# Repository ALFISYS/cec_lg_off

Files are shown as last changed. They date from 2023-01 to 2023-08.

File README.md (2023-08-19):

# cec\_lg\_off

**cec\_lg\_off** is a hardware addon to make old LG smart TVs with WebOS be able to be turned off with command over HDMI device connected to it. 

It is a tiny device that you connect to your TV's interfaces. 

**cec\_lg\_off** monitors commands that other devices connected to your TV over HDMI, and when it detects someone sent CEC `STANDBY` command to TV, it turns off TV

### Device photos

#### Working prototype.

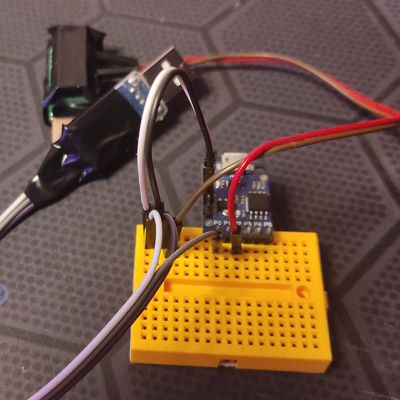
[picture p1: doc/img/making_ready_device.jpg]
Prototype


*brown wire connected wrong hole on this photo. Is should be connected to 2nd column (black wires)*

### Making of device

All process of building this device from AliExpress modules is described in ["making  from modules" document](doc/MAKING_MODULES.md).

### Questions

#### *Do I need to connect the device to the HDMI cable break?*

No. You need to connect it to any free HDMI port on your TV. Control commands are sent over HDMI CEC line (Pin13 on HDMI cable). This line is electrically connected together through all HDMI devices that connected together. This means when some device talks using CEC to other device, everyone hear them.

#### *Can I connect USB cable to power adapter or power bank?*

No. You need to connect it to any free USB port on your TV. When device detects STANDBY command sent to TV on CEC line, it sends equal command (power off) through USB-SERIAL adapter. Also device powers from it. 

### Bill of materials (BOM) / List of materials (LOM)

Materials for building device from modules are listed in separate [List of materials (LOM) document](doc/LOM_MODULES.md).

### Building firmware

It's recommended to configure MCU to run at 16 MHz (`F_CPU = 16000000`).
If you're using **DigiSpark USB**, configuration supports 16.5 MHz CPU.
For other `F_CPU` values, please add your F_CPU to PowerShell script [helper_constants.ps1](firmware/attiny25/helper_constants.ps1) and run it to get contents for [constants.h](firmware/attiny25/src/cec_mon_constants.h).

### Other documents

Documents used while developing this device, such as MCU datasheet, HDMI specification, etc. are located under [`doc`](doc) folder. 

### CEC emulator

A tiny emulator that sends STANDBY command periodically is located as Arduino project under [`cec_emulator_firmware`](cec_emulator_firmware) folder

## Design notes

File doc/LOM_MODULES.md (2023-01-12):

# cec\_lg\_off LOM for DIY device from modules.

### List of materials (LOM) for device

Same as BOM, but with instructions and no prices.

* **PL2303** USB-TTL (USB-SERIAL) adapter.
	* ⚠️ **WARNING**: PL2303HX, PL2303TA are recommended. Non-PL* alternatives are not allowed.
	* Before buying next, ensure your adapter has VID 067B and PID 2303
	* Before buying next, ensure your TV recognizes PL2303 adapter
		* Turn TV on
		* Plug PL2303 adapter into TV USB port
		* Ensure message apperared without words like "unknown" or "unrecognized"
	* Links: [🔗 AliExpress](https://aliexpress.com/item/32531899568.html)
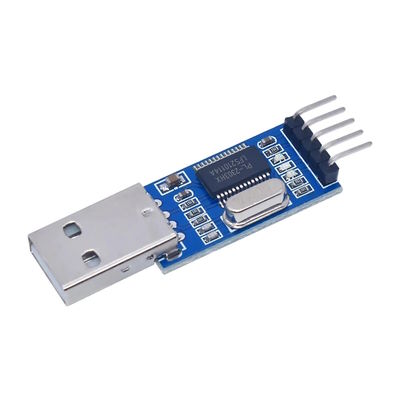
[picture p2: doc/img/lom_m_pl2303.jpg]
PL2303 USB-TTL Board
	* Image: 
* **DigiSpark USB** developement board
	* Prefer board with female USB connector.
	* Links: [🔗 AliExpress](https://aliexpress.com/item/32584084654.html), [🔗 AliExpress](https://aliexpress.com/item/32807895683.html)
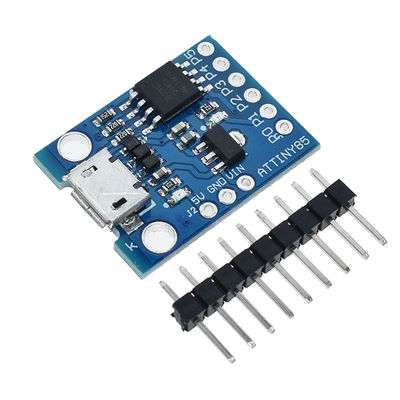
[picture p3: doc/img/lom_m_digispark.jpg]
Digispark Attiny85 dev board
	* Image: 
* **HDMI A male connector with screw terminals**
	* Links: [🔗 AliExpress](https://aliexpress.com/item/1005001515985184.html)
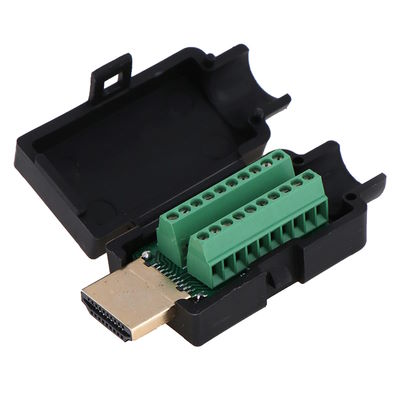
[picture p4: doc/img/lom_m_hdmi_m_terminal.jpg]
HDMI male connector withj screw terminals
	* Image: 
* **Solderless mini breadboard**
	* Links: [🔗 AliExpress](https://aliexpress.com/item/32649320530.html)
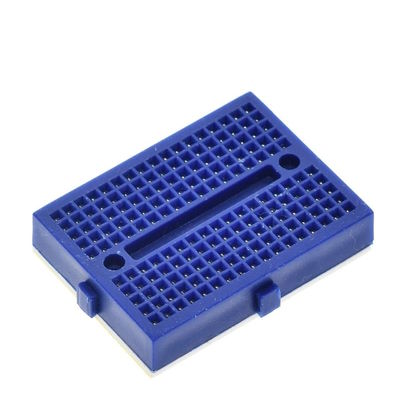
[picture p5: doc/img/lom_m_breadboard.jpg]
Solderless mini breadboard
	* Image: 
* **DuPont cables**
	* You'll need 2 long cables `male-male` and 5 `male-female`
	* Links: [🔗 AliExpress](https://aliexpress.com/item/32825558073.html)
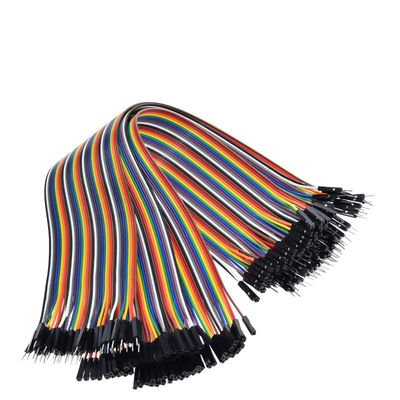
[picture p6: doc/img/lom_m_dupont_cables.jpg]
	* Image: 
* Some good insulating tape
* Soldering iron

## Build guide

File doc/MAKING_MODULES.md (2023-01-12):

### Bill of materials (BOM) / List of materials (LOM)

Materials for building device from modules are listed in separate [List of materials (LOM) document](LOM_MODULES.md).

### Device photos



*brown wire connected wrong hole on this photo. Is should be connected to 2nd column (black wires)*

### Making of device

* Ensure your TV is LG and it supports SimpLink (HDMI CEC).
* Ensure device connected supports HDMI CEC: device must react to commands from TV Remote.
* Ensure your TV runs WebOS
* Ensure you have free USB port on your TV
* Ensure you have free HDMI port on your TV
* Buy PL2303 USB Adapter
* Insert PL2303 USB Adapter into USB port of your TV and ensure it is recognized by TV (message about USB device should appear, without *unrecognized* word)
* Order rest of modules.
* Solder pins to DigiSpark
* Assemble by scheme
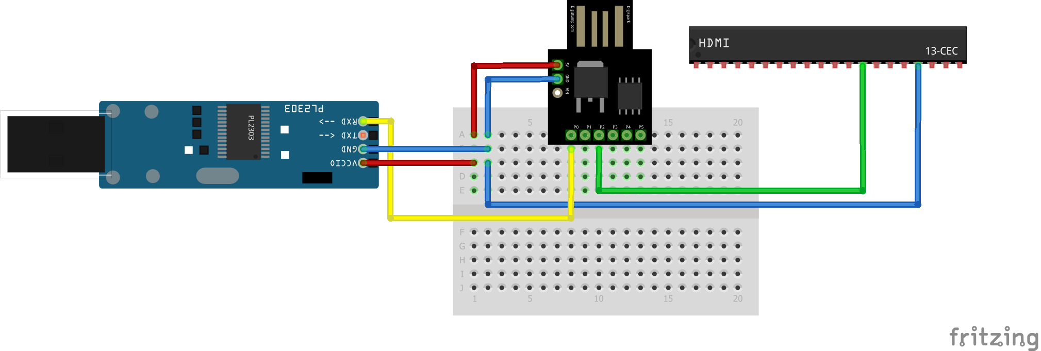
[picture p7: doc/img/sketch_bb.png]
	*   
* Flash firmware
* Isolate unisolated parts, tape mechanically bad contacts
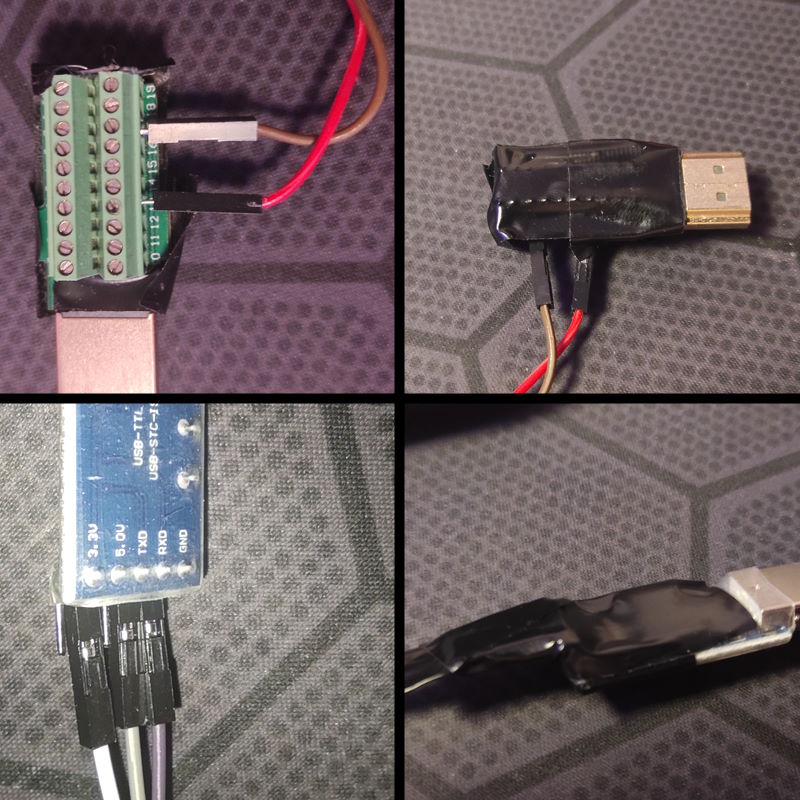
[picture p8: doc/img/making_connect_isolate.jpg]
	* 
* Isolate DigiSpark USB connector with tape to avoid using it while connected to TV.
* Connect to TV: USB to USB, HDMI to HDMI
* Test: make any device send STANDBY command to TV. When command received by `cec_lg_off`, it will shortly flash with onboard red led.

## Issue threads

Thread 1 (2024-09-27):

Sometimes seems to prevent other CEC operation

sambrightman, 2024-09-27:
Hi, great project. I have built it and it works. However, once the TV is off I am finding that power-on of a playback device will no longer power on the receiver and TV and switch source as it normally does.

[Potentially inaccurate information] My memory is that everything was working when I first built it, and that a [subsequent attempt](https://github.com/ArminJo/micronucleus-firmware/issues/33) to upgrade micronucleus roughly coincided with problems starting. Of course the code from this project remains the same.

Do you have any idea why this would happen, or any debugging steps to suggest?

filimonic, 2024-10-10:
As for debugging steps I'd recommend cheap chineese logic analyzer. Then with sigrok you can monitor CEC line to know what happens. Sorry, no time for this now.

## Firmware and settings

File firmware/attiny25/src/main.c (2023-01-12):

/*
 * This file is part of cec_lg_off.
 * This work is licensed under the Creative Commons Attribution-NonCommercial-ShareAlike 3.0 Unported License. 
 * To view a copy of this license, visit http://creativecommons.org/licenses/by-nc-sa/3.0/ or send a letter to Creative Commons, PO Box 1866, Mountain View, CA 94042, USA.
*/

/**
 * WARNING!
 * When connecting this board to anything except HDMI, physically disconnect HDMI. You can damage your TV.
 * 
 * PINS Used: 
 * * PB2 (P2 on Digispark USB) - HDMI CEC Line, connected to HDMI Pin 13 (CEC)
 * * PB0 (P0 on Digispark USB) - TX. Connected to RX on PL2303
*/
#include "./config.h"
#include <avr/io.h>
#include <avr/interrupt.h>
#include <avr/wdt.h>
#include <inttypes.h>
#include <avr/sleep.h>
#include "./cec_mon.h"
#include "./uart_send.h"





void setup();
void disable_wdt();
volatile void process_cec_message(tinycec_message_t *, uint8_t, uint8_t);


#define SEND_NOTHING   ((uint8_t)0)
#define SEND_POWER_CMD ((uint8_t)1)


uint8_t send_status_flag = 0;

int main() 
{
  setup();


  
  send_status_flag = SEND_NOTHING;
  tinycec_start(process_cec_message);
  sei();
  do 
  {
    if (send_status_flag == SEND_POWER_CMD) 
    {
      PORTB |= (uint8_t)(1 << PB1); // Indicator ON
      cli();
      send_status_flag = SEND_NOTHING;
      send_uart_cmd(PWROFF_UART_CMD);
      sei();
      PORTB &= (uint8_t)~(1 << PB1); // Indicator OFF
    }
    sleep_enable();
    sleep_cpu();
    sleep_disable();
  }
  while(1);
}

uint8_t tmp_buf[256];
volatile void process_cec_message(tinycec_message_t * message, uint8_t message_len, uint8_t message_ack)
{
  //send_ir_cmd(0);
  if (
    message_len > 0 &&
    message->data.opcode == CEC_OPCODE_STANDBY &&
    (
      message->data.destination_addr == CEC_ADDRESS_TV ||
      message->data.destination_addr == CEC_ADDRESS_BROADCAST))
  {
    send_status_flag = SEND_POWER_CMD;
  }
}


void disable_wdt()
{
  wdt_reset();
  MCUSR = (uint8_t)0x00;
  // WDT should be disabled exactly this way.
  WDTCR |= (uint8_t)((1<<WDCE) | (1<<WDE));
  WDTCR = (uint8_t)0x00; // This command must be executed within 4 cycles after previous
}


void setup()
{
  // Disable all interrupts while setup
  cli(); 

  // Disable watchdog.
  disable_wdt(); 

  // Disable power for USI, ADC, Timer1 subsystems.
  PRR = (uint8_t)((1 << PRADC) | (1 << PRUSI) |  (1 << PRTIM1)); 

  // Disable Pull-Up resistor on all pins & set Pin Change interrupts to fire at any pin change
  MCUCR |= (uint8_t)((1 << PUD) | (1 << ISC00)); 

  // Set PB0=TX as output, PB1=LED as output, others (including PB2=CEC) are input.
  DDRB = (uint8_t)((1 << PB0) | (1 << PB1)); 

  // Set PB0 to high
  PORTB |= (uint8_t)(1 << PB0);

  // Enable interrupts for PB2=CEC pin
  PCMSK = (1 << PB2);

  set_sleep_mode(SLEEP_MODE_IDLE);
}

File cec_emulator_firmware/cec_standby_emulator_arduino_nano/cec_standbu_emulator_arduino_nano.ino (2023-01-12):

/*
 * This file is part of cec_ir_off.
 * This work is licensed under the Creative Commons Attribution-NonCommercial-ShareAlike 3.0 Unported License. 
 * To view a copy of this license, visit http://creativecommons.org/licenses/by-nc-sa/3.0/ or send a letter to Creative Commons, PO Box 1866, Mountain View, CA 94042, USA.
*/

inline void cec_low(uint16_t delay)
{
  digitalWrite(12, LOW);
  digitalWrite(13, LOW);
  
  delayMicroseconds(delay);
}

inline void cec_high(uint16_t delay)
{
  digitalWrite(12, HIGH);
  digitalWrite(13, HIGH);
  
  delayMicroseconds(delay);
}

void setup() 
{
  pinMode(12, OUTPUT);
  pinMode(13, OUTPUT);
  cec_high(0);
}

void cec_send( uint8_t bytes[], uint8_t length ) 
{
  // Start Bit
  cec_low(3700);
  cec_high(4500-3700);

  for (uint8_t i_byte = 0; i_byte < length; i_byte++)
  {
    uint8_t b = bytes[i_byte];
    for (uint8_t i_bit = 0; i_bit < 10; i_bit++)
    {
      uint8_t bit = 1;
      if (i_byte == length - 1 && i_bit == 8) // EOM
      {
        bit = 1;
      }
      else if (i_bit < 8)
      {
        bit = b >> 7 & 0x01;
        b = b << 1;
      }
      else if (i_bit == 9) {
        bit = 0;
      } else 
      {
        bit = 0;  
      }

      if (bit == 1)
      {
        cec_low(600);
        cec_high(2400-600);
      }
      else
      {
        cec_low(1500);
        cec_high(2400-1500);
      }
    }
  }

}



void loop() {
  byte off[] = {0xF0, 0x36};
  
  
  cec_send(off, 2);
  delay(1000);

  //byte png[] = {0xF0, 0x00, 0x00, 0x00, 0x00, 0x00};
  //cec_send(png, 6);
  //delay(3000);
  
  

}
